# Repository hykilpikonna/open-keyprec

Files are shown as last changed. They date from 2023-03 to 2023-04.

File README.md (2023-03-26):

<h1 align="center">
  <br>
  <br>
  Open-KeyPrec
  <h4 align="center">
  Open-Sourced Electric Keyboard Percussion Instrument
  </h4>
  <h5 align="center">
<a href="#code">Code</a>&nbsp;&nbsp;
<a href="#build">Build</a>&nbsp;&nbsp;
<a href="#usage">Usage</a>&nbsp;&nbsp;
<a href="#license">License</a>
</h5>
  <br>
  <br>
  <br>
</h1>

## About

Open-KeyPrec is an open-sourced, pressure-sensitive electric keyboard percussion (mallet) MIDI instrument. It has 61 keys, spanning 5 octaves of playing range from C2 to C7 like a standard Marimba. It also has a MIDI control panel with 16 buttons, 12 knobs (8 × 280° potentiometers and 4 × 360° rotary encoders).

The sensors are controlled by a development board, and the output is converted into a standard MIDI device. You can use audio workstation softwares like GarageBand or Reaper (or open-source alternatives like LMMS, Zrythm, or Ardour) to simulate the sounds of all kinds of different instruments.

## Code

**Source code structure**

* `/src` - PC driver written in Rust
* `/firmware` - Development board firmware written in C++
* `/circuits` - Printed circuit boards
* `/models` - 3D-printable models

**Toolchains & Environments Used**

* EasyEDA: Web-editor for creating circuit boards
* FreeCAD: Software for designing mechanical 3D models
* CLion: IDE for Rust & C++
* PlatformIO: Firmware development toolkit

**Pin Configuration**

| Pins | I/O | Description |
|---|-----|---|
| 4 | O | Mux Select for C2-B6 |
| 5 | IA  | Mux Input for C2-B6 |
| 1 | IA  | Input for C7 |
| 8 | I | (Panel) Input for 4 rotary encoders |
| 3 | O | Mux Select for buttons and potentiometers |
| 2 | I | Mux Input for buttons |
| 1 | IA  | Mux Input for potentiometers |
| 3 | O | RGB LED Control |

Total ADC channels required: 7
Total GPIO required: 23

## Build

### Materials Required

!!!!!!!!!! TODO !!!!!!!!!!

### Tools Required

* FDM 3D Printer (~$300 Ender 3 is fine)
* Soldering kit (iron, solder, flux)
* Wood Saw
* A computer

### 1. Order PCBs

I ordered my PCBs from JLC, but any PCB service would work. They should accept the exported Gerber zip files in `circuits/Exports` folder.

I created two circuit boards for this keyboard, one is the multiplexer ([Mux v2.zip](circuits/Mux%20v2.zip)) which uses the CD74HC4067 1:16 multiplexer ic to convert the 61 separate analog inputs requirement into only 5 analog inputs and 4 digital switch outputs. 
It also haso diodes and resistors for voltage protection. The other pcb ([OKP-Panel-SMT.zip](circuits/OKP-Panel-SMT.zip)) is for the MIDI control panel containing the buttons and knobs.

1. Go to jlcpcb.com (Or jlc.com if you read Chinese)
2. Upload the Gerber file
3. Set parameters: FR-4, 2 Layers, Color, leave default for other options

**PCB Assembly (SMT)**

If you're not comfortable soldering small SMD components, you can order PCB Assembly from JLC. 
You can also select which parts you would like to SMT based on your soldering abilities. 
For example, in the Mux pcb, I ordered SMT for only the 0603 Zener diodes and the CD74HC4067 ic, and hand-soldered everything else.

1. Order "PCB Assembly" (SMT) and click confirm
2. In the SMT menu, upload the BOM and CPL (PickAndPlace) files
3. After uploading, remove the parts you want to manually solder (they're pretty expensive, since someone in the factory still have to manually solder them for you)
4. Order manually-soldered parts somewhere else (e.g. szlcsc.com)

## Usage

### Flash Firmware

1. Install PlatformIO Core ([Guide](https://platformio.org/install/cli))
2. Open the `firmware` directory
3. In your preferred IDE, edit `src/config.h` with your pin configuration.
4. Edit `platformio.ini` to match your dev board.
5. Connect dev board, build and upload firmware using `platformio run --target upload`

### Setup MIDI Device

!!!!!!!!!! TODO !!!!!!!!!!

### Setup Audio Softwares

A MIDI keyboard doesn't make sound on its own. To actually play an instrument, you would need an audio workstation software and some VST sound sources.

Notation: 🍎 - macOS, 🪟 - Windows, 🐧 - Linux

#### Free Mallet Sound Sources

**Built-in Sources**

* GarageBand comes with marimba, vibraphone, and glockenspiel sound sources. It's free but macOS only and does not have VST support.
* LMMS comes with several mallet instruments.

**External Plugins**

| Name & Link | Author | Platforms | Formats |
| --- | --- | --- | --- |
| [Alto Glockenspiel](https://www.steinberg.net/vst-instruments/alto-glockenspiel/) | Steinberg | 🍎 🪟 | VST, AU |
| [Marimbaphonic](http://www.alanvista.com/marimbaphonic/) | Alan Vista | 🍎 🪟 | VST, AU |
| [VibroMaster](http://www.alanvista.com/vibromaster/) | Alan Vista | 🍎 🪟 | VST, AU |
| [DSK Virtuoso](https://www.dskmusic.com/dsk-virtuoso/) (Celesta, Glockenspiel, ...) | DSK Music | 🪟 | VST |

Unfortunately there aren't any free VSTs supporting linux that I can find. You have to use Windows for this one if you don't have a mac/hackintosh. If you found any additional VSTs, feel free to make a PR!

Other free VST Plugins: https://github.com/webprofusion/OpenAudio

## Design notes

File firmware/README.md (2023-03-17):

## Run

### View logs

* `screen /dev/cu.usbserial-142140 9600`
* Use `↓Ctrl ↓a ↑a ↓\ ↑\` to exit.

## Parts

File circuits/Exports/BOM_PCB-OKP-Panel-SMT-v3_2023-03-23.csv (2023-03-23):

ID | Name | Designator | Footprint | Quantity | Manufacturer Part | Manufacturer | Supplier | Supplier Part | Price | Pins | 3DModel | Contributor | Resistance (Ohms) | description | image | link
1 | 74HC4051PW,118 | BTN-MUXC,BTN-MUXC1,P-MUX | TSSOP-16_L5.0-W4.4-P0.65-LS6.4-BL | 3 | 74HC4051PW,118 |  | LCSC | C5645 | 0.027 | 16 | TSSOP-16_L5.0-W4.4-H1.0-LS6.4-P0.65 | lcsc |  | 8-Channel Analog MultiplexerDemultiplexer |  | https://item.szlcsc.com/6534.html
2 | XL-5050RGBC-WS2812B | LED1,LED2,LED3,LED4,LED9,LED10,LED11,LED12,LED13,LED14,LED15,LED16,LED17,LED18,LED19,LED20,LED21,LED22,LED23,LED24 | LED-SMD_4P-L5.0-W5.0-BL_XL-5050RGBC | 20 |  |  | LCSC | C2843785 | 0.008 | 4 | LED-SMD_4P-L5.0-W5.0-BL_XL-5050RGBC | LCSC |  |  |  | https://atta.szlcsc.com/upload/public/pdf/source/20210708/C2843785_2CEFABF204E2EF27FCE5F6F9FD929633.pdf
3 | KEY-TH_4P-L6.0-W6.0-P4.50-LS6.5 | KEY5,KEY6,KEY7,KEY8 | KEY-TH_4P-L6.0-W6.0-P4.50-LS6.5 | 4 | K2-1102DP-E4SW-04 | 韩国韩荣 | LCSC | C136684 | 0.007 | 4 | KEY-TH_4P-L6.0-W6.0-P4.50-LS6.5 | lcsc |  |  |  | https://item.szlcsc.com/111374.html
4 | K4-6×6_TH | B1,B2,B3,B4,B5,B6,B7,B8 | KEY-TH_4P-L6.0-W6.0-P4.50-LS6.5 | 8 | K2-1102DP-E4SW-04 | 韩国韩荣 | LCSC | C136684 | 0.007 | 4 | KEY-TH_4P-L6.0-W6.0-P4.50-LS6.5 | LCEDA_Lib |  |  |  | https://item.szlcsc.com/111374.html
5 | B3F-4055 | KEY1,KEY2,KEY3,KEY4 | KEY-TH_4P-L12.0-W12.0-P5.00-LS13.4-EH | 4 | B3F-4055 | OMRON(欧姆龙) | LCSC | C84931 | 0.015 | 4 | KEY-TH_4P-L12.0-W12.0-H7.5-LS12.5-P5.0 | lcsc |  |  |  | https://item.szlcsc.com/84377.html
6 | 10kΩ | P1,P2,P3,P4,P5,P6,P7,P8 | RES-ADJ-TH_RK09D1130C4G | 8 | RK09D113000F | ALPSALPINE(阿尔卑斯阿尔派) | LCSC | C470317 | 0.088 | 5 | RES-ADJ-TH_RK09D1130C4G | lcsc |  |  |  | https://atta.szlcsc.com/upload/public/pdf/source/20210222/C2687325_4FFD17AAA104A4955DD1E89BBAB92083.pdf
7 | HDR-M-2.54_1x2 | POWER(5V),POWER2 | HDR-M-2.54_1X2 | 2 |  |  | LCSC | C124375 | 0.004 | 2 | HDR-M-2.54_1x2 | LCEDA_Lib
8 | HDR-M-2.54_2x4 | ROTERY | HDR-M-2.54_2X4 | 1 |  |  | LCSC | C58363 |  | 8 | HDR-M-2.54_2x4 | LCEDA_Lib
9 | EC12E24204A8 | SW1,SW2,SW3,SW4 | SW-TH_EC12EXXXX | 4 | EC12E24204A8 | ALPSALPINE(阿尔卑斯阿尔派) | LCSC | C470598 | 0.091 | 5 | SW-TH_EC12EXXXX-L13.2-W12.4-H20.0-P2.5-LS14.0 | LCSC |  |  |  | https://item.szlcsc.com/476763.html?ref=editor&logined=true
10 | HDR-M-2.54_2x3 | MUX-SEL | HDR-M-2.54_2X3 | 1 |  |  | LCSC | C65114 | 0.005 | 6 | HDR-M-2.54_2x3 | LCEDA_Lib
11 | 10kΩ | PU1,PU2,PU3,PU4,PU5,PU6,PU7,PU8,R1,R2 | R0603 | 10 |  |  | LCSC |  |  | 2 | R0603_L1.6-W0.8-H0.8 | LCSC |  |  |  | https://item.szlcsc.com/137208.html
12 | 1Ω | QWQ | R0603 | 1 | MF1/4W-200KΩ±1% T | CCO(千志电子) | LCSC | C119373 | 0.002 | 2 | R0603_L1.6-W0.8-H0.8 | LCSC | 200K |  |  | https://item.szlcsc.com/137208.html
13 | 1kΩ | R3 | R0603 | 1 |  |  | LCSC |  |  | 2 | R0603_L1.6-W0.8-H0.8 | LCSC |  |  |  | https://item.szlcsc.com/137208.html
14 | 3.3kΩ | R4 | R0603 | 1 |  |  | LCSC |  |  | 2 | R0603_L1.6-W0.8-H0.8 | LCSC |  |  |  | https://item.szlcsc.com/137208.html
15 | HDR-M-2.54_1x3 | LED | HDR-M-2.54_1X3 | 1 |  |  | LCSC | C180248 | 0.031 | 3 | HDR-M-2.54_1x3 | LCEDA_Lib

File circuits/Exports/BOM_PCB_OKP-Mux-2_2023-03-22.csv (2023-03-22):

ID | Name | Designator | Footprint | Quantity | Manufacturer Part | Manufacturer | Supplier | Supplier Part | Price | Pins | 3DModel | Contributor | Resistance (Ohms) | link
1 | HDR-M-2.54_1x2 | OUT1,OUT | HDR-M-2.54_1X2 | 2 |  |  | LCSC | C124375 | 0.004 | 2 | HDR-M-2.54_1x2 | LCEDA_Lib
2 | M1250V-02P | A,A#,B,C,C#,D,D#,E,EX1,EX2,EX3,EX4,F,F#,G,G# | CONN-TH_2P-P1.25_HCTL_HC-1.25-2AW | 16 | M1250V-02P | XFCN(兴飞) | LCSC | C481432 | 0.002 | 2 | CONN-TH_2P-P1.25_HCTL_HC-1.25-2AW | LCSC |  | https://atta.szlcsc.com/upload/public/pdf/source/20210729/C2845535_17B4C65D5133EDBE0A07B8E05D9E3662.pdf
3 | 5.1v | D9,D10,D11,D12,D13,D14,D15,D16,D1,D2,D3,D4,D5,D6,D7,D8 | SOD-123_L2.8-W1.8-LS3.7-RD | 16 | 1N4007W | BLUE ROCKET | LCSC | C328592 | 0.001 | 2 | SOD-123_L2.8-W1.8-LS3.7-RD | LCEDA_Lib |  | https://item.szlcsc.com/301422.html
4 | HDR-M-2.54_1x6 | SEL-NEXT,SEL-PREV | HDR-M-2.54_1X6 | 2 |  |  | LCSC | C190819 | 0.006 | 6 | HDR-M-2.54_1x6 | LCEDA_Lib
5 | CD74HC4067M96 | UWU | SOIC-24_L15.4-W7.5-P1.27-LS10.3-BL | 1 | CD74HC4067M96 | TI(德州仪器) | LCSC | C496123 | 0.163 | 24 | SOIC-24_L15.4-W7.5-H2.7-LS10.3-P1.27 | LCSC |  | https://item.szlcsc.com/417060.html
6 | 47kΩ | R1,R2 | RES-TH_BD2.2-L6.5-P10.50-D0.6 | 2 | MF1/4W-47KΩ±1% T | CCO(千志电子) | LCSC | C119362 | 0.002 | 2 | RES-TH_BD2.2-L6.5-P10.50 | LCSC | 47K | https://item.szlcsc.com/59661.html

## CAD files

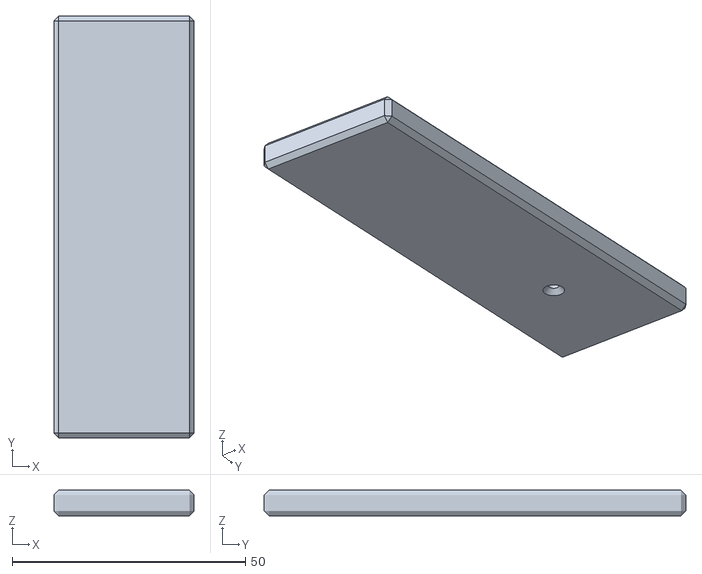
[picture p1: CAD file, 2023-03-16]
models/Exports/50-C#6.stl
30.0 x 90.3 x 5.50

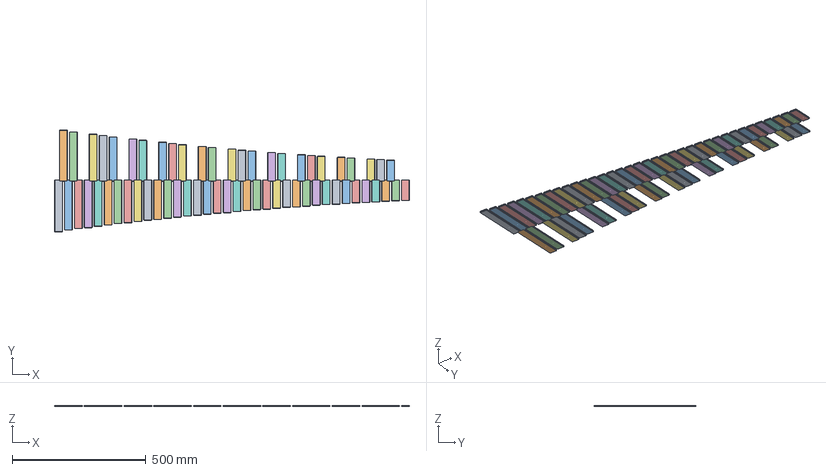
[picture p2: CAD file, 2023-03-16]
models/v4-filled.FCStd
1325.0 x 379.1 x 5.50 mm
C2-Base
C#2-Base
D2-Base
D#2-Base
E2-Base
F2-Base
F#2-Base
G2-Base
G#2-Base
A2-Base
A#2-Base
B2-Base
C3-Base
C#3-Base
D3-Base
D#3-Base
E3-Base
F3-Base
F#3-Base
G3-Base
G#3-Base
A3-Base
A#3-Base
B3-Base
C4-Base
C#4-Base
D4-Base
D#4-Base
E4-Base
F4-Base
F#4-Base
G4-Base
G#4-Base
A4-Base
A#4-Base
B4-Base
C5-Base
C#5-Base
D5-Base
D#5-Base
E5-Base
F5-Base
F#5-Base
G5-Base
G#5-Base
A5-Base
A#5-Base
B5-Base
C6-Base
C#6-Base
D6-Base
D#6-Base
E6-Base
F6-Base
F#6-Base
G6-Base
G#6-Base
A6-Base
A#6-Base
B6-Base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

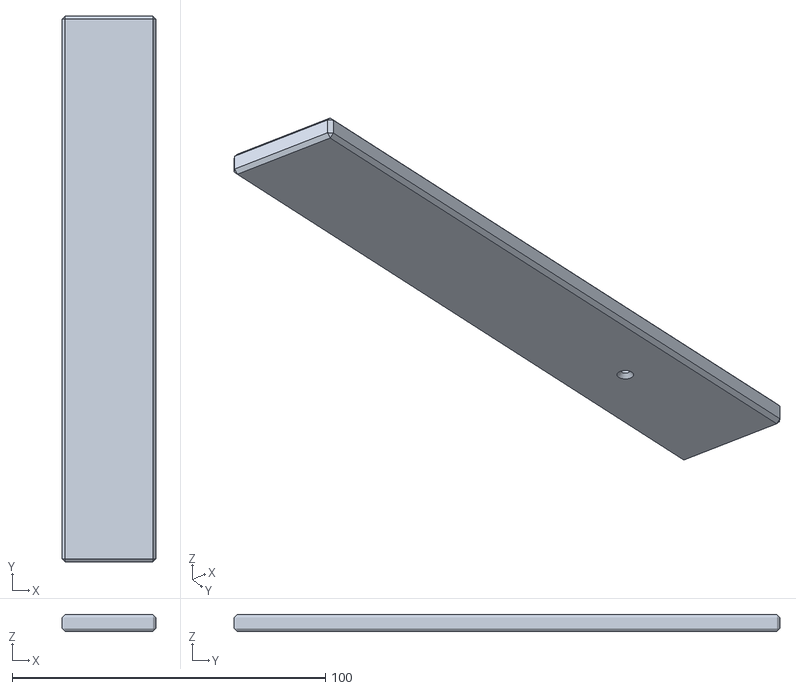
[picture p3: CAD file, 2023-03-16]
models/Exports/08-G2.stl
30.0 x 174.3 x 5.50

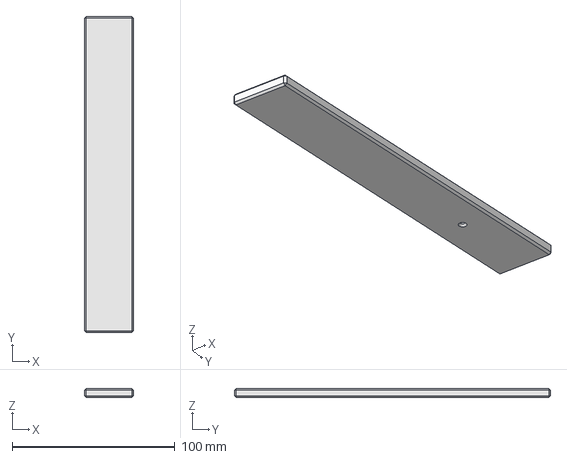
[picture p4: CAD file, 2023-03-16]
models/v4.FCStd
30.0 x 194.0 x 5.50 mm

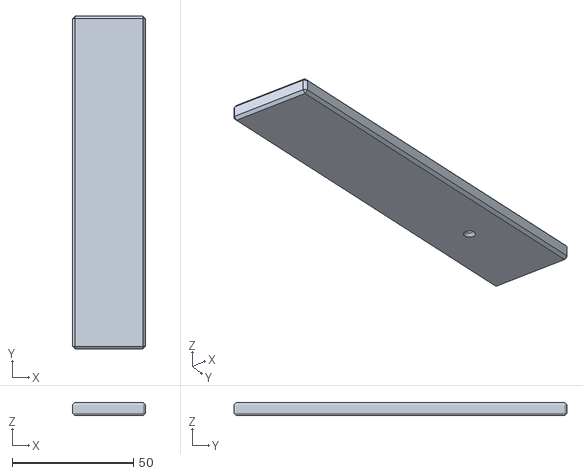
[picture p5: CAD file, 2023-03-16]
models/Exports/23-A#3.stl
30.0 x 137.6 x 5.50

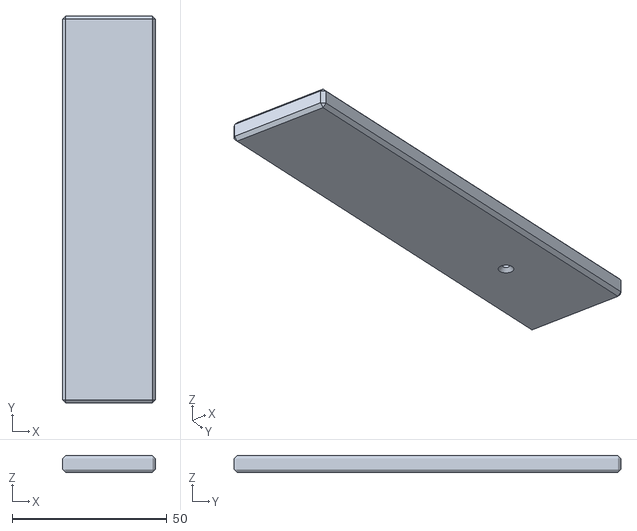
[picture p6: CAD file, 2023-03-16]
models/Exports/29-E4.stl
30.0 x 125.0 x 5.50

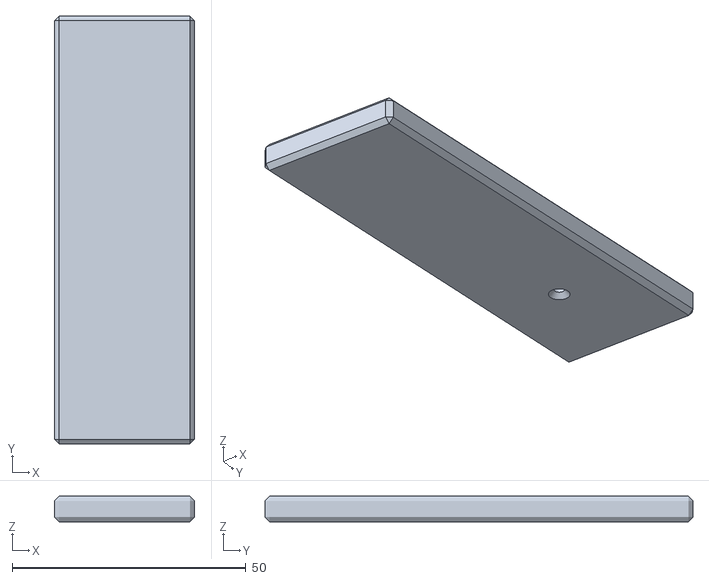
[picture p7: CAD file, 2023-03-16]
models/Exports/49-C6.stl
30.0 x 91.6 x 5.50

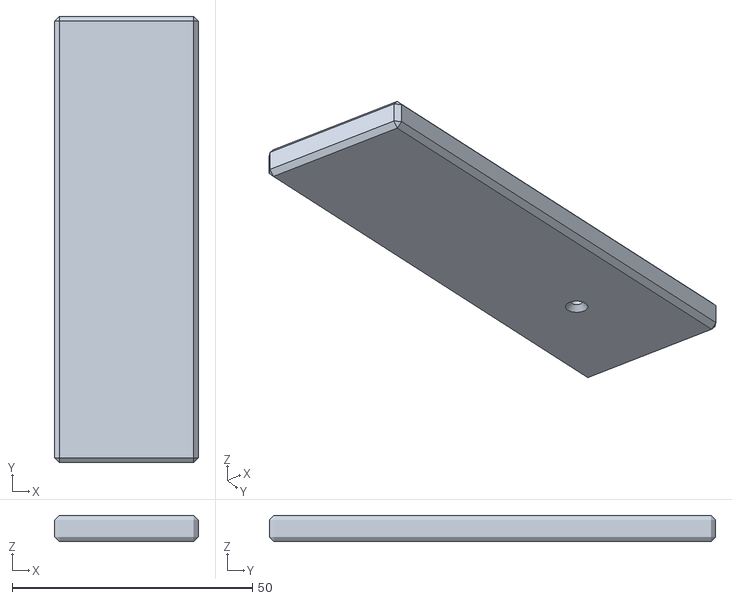
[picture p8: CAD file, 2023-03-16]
models/Exports/48-B5.stl
30.0 x 93.0 x 5.50

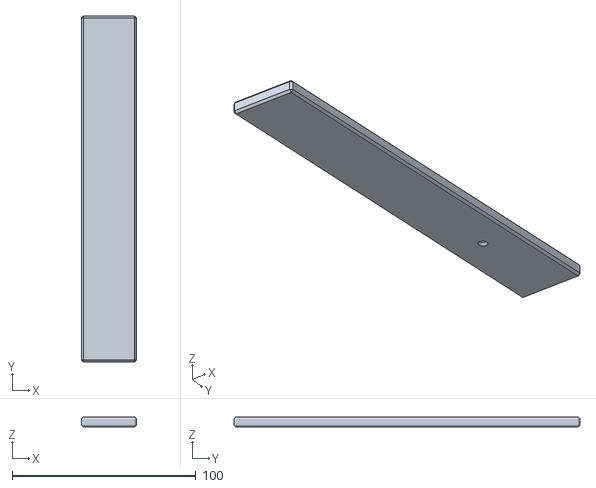
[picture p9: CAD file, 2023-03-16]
models/Exports/03-D2.stl
30.0 x 188.2 x 5.50

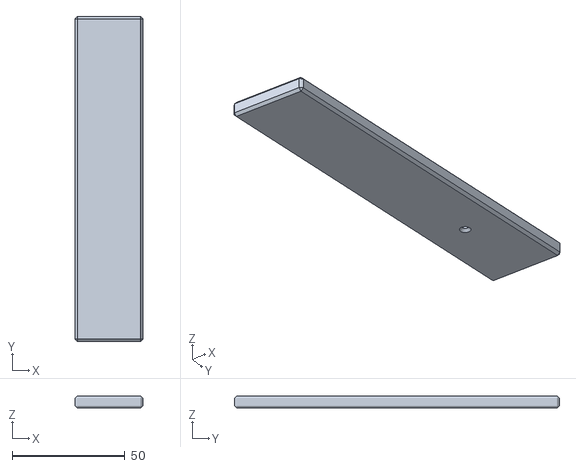
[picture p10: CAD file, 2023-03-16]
models/Exports/20-G3.stl
30.0 x 144.3 x 5.50

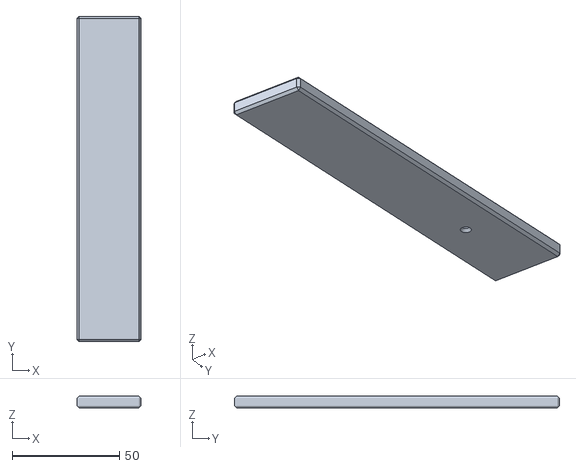
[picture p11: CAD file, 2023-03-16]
models/Exports/17-E3.stl
30.0 x 151.4 x 5.50

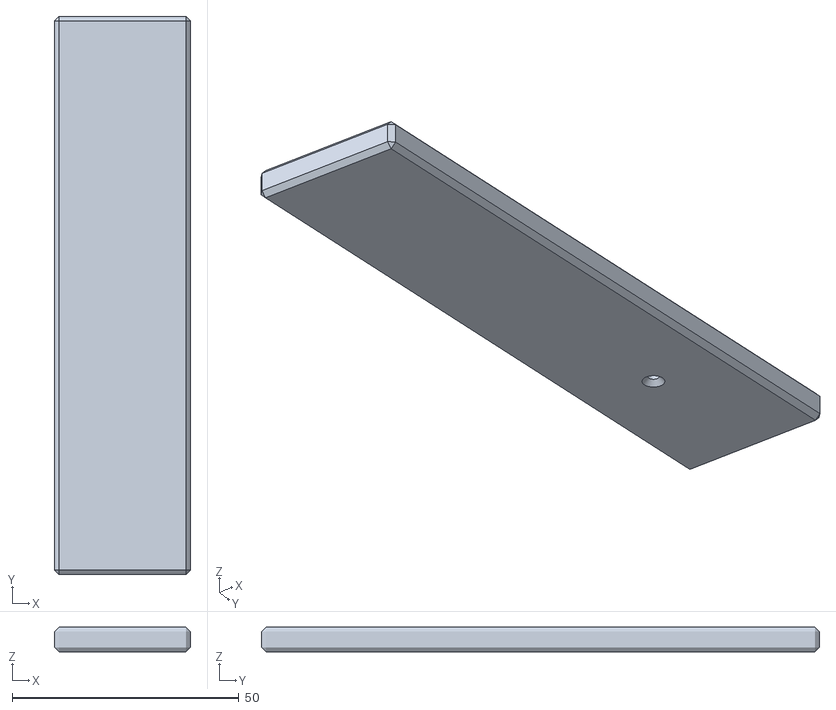
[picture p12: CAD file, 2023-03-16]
models/Exports/30-F4.stl
30.0 x 123.0 x 5.50

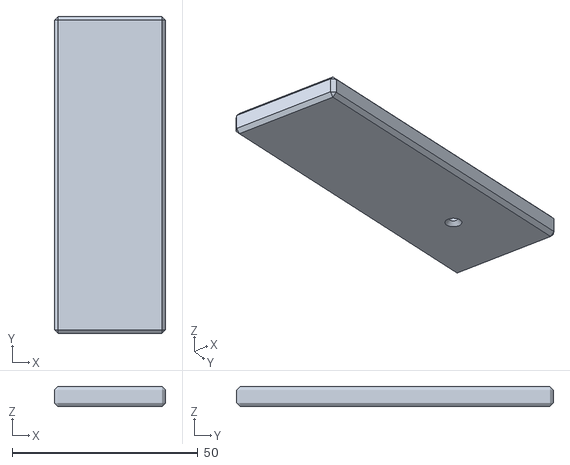
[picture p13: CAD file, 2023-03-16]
models/Exports/54-F6.stl
30.0 x 85.4 x 5.50

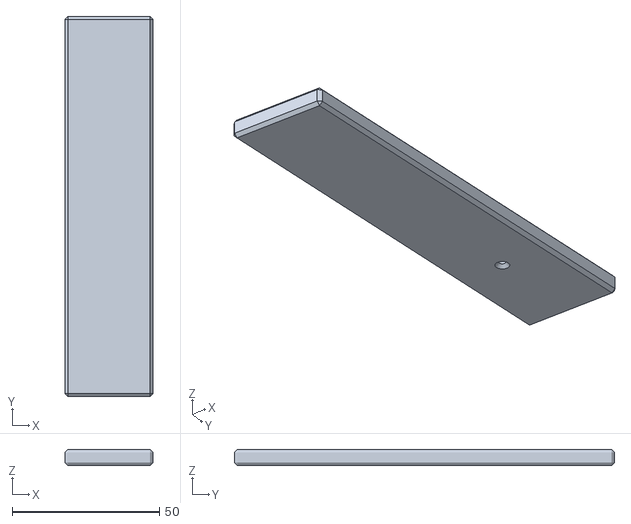
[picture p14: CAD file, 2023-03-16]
models/Exports/27-D4.stl
30.0 x 129.1 x 5.50

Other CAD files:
models/Exports/09-G#2.stl
models/Exports/45-G#5.stl
models/Exports/42-F5.stl
models/Exports/22-A3.stl
models/Exports/01-C2.stl
models/Exports/02-C#2.stl
models/Exports/04-D#2.stl
models/Exports/05-E2.stl
models/Exports/06-F2.stl
models/Exports/07-F#2.stl
models/Exports/10-A2.stl
models/Exports/11-A#2.stl
models/Exports/12-B2.stl
models/Exports/13-C3.stl
models/Exports/14-C#3.stl
models/Exports/15-D3.stl
models/Exports/16-D#3.stl
models/Exports/18-F3.stl
models/Exports/19-F#3.stl
models/Exports/21-G#3.stl
models/Exports/24-B3.stl
models/Exports/25-C4.stl
models/Exports/26-C#4.stl
models/Exports/28-D#4.stl
models/Exports/31-F#4.stl
models/Exports/32-G4.stl
models/Exports/33-G#4.stl
models/Exports/34-A4.stl
models/Exports/35-A#4.stl
models/Exports/36-B4.stl
models/Exports/37-C5.stl
models/Exports/38-C#5.stl
models/Exports/39-D5.stl
models/Exports/40-D#5.stl
models/Exports/41-E5.stl
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

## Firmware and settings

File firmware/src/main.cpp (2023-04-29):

#include <Arduino.h>
#include "config.h"
#include "Adafruit_NeoPixel.h"
#include "main.h"
#include "utils.h"
#include "panel.cpp"
#include "keyboard_lights.cpp"

u32 lasts[NUM_NOTES];  // variable to store the value coming from the sensor
u64 last_hit_times[NUM_NOTES];
u32 bounce_delay = 50; // Minimum time between two hits

let max_sensor = 4096;
let max_threshold = 3000;
let active_threshold = 400;  // Minimum value to be considered as a hit

let led_refresh_on = false;

Panel panel;
KeyboardLights keyboardLights;

void setup()
{
    // Initialize pins
    pinModeSafe(LED_REFRESH, OUTPUT);
    for (int pin: MUX_IN) pinModeSafe(pin, INPUT);
    for (int pin: MUX_SEL_OUT) pinModeSafe(pin, OUTPUT);

    // Initialize serial
    Serial.begin(115200);
    Serial.printf("Initialized\r\n");

    panel.begin();
    keyboardLights.begin();
}

u64 fps_last_update = 0;
u32 fps_updates = 0;
const u32 fps_interval_ms = 1000;

void countFps(u64 time)
{
    // Report FPS every second
    fps_updates++;
    if (time - fps_last_update >= fps_interval_ms)
    {
        fps_last_update = time;
        double fps = 1.0 * fps_updates / fps_interval_ms * 1000;
        Serial.printf("FPS: %.2f\r\n", fps);
        fps_updates = 0;
    }
}

void readKeyboard()
{
    u64 time = millis();
    countFps(time);

    // Toggle LED refresh indicator
    digitalWrite(LED_REFRESH, led_refresh_on = !led_refresh_on);

    // Loop through each multiplexer state
    for (int i = 0; i < PINS_PER_MUX; i++)
    {
        // Set select pins
        for (int j = 0; j < NUM_MUX_SEL; j++)
        {
            // i >> j is the jth bit of i
            digitalWrite(MUX_SEL_OUT[j], (i >> j) & 1);
        }

        // Read input pins from the multiplexer
        for (int j = 0; j < NUM_MUX; j++)
        {
            int note_id = j * PINS_PER_MUX + i;
            if (note_id >= NUM_NOTES) break;

            // Read the analog input
            u32 v = analogRead(MUX_IN[j]);
            if (v != lasts[note_id])
            {
                on_sensor_update(note_id, time, lasts[note_id], v);
            }
            lasts[note_id] = v;
        }
    }
}

/**
 * Called when the sensor value changes
 *
 * @param id Sensor index
 */
void on_sensor_update(int id, u64 time, u32 last, u32 current)
{
    // If the last hit is too close, ignore this hit
    let last_hit_time = last_hit_times[id];
    if (time - last_hit_time < bounce_delay) return;

    // If the value is above the threshold
    if (current > active_threshold)
    {
        // If the last value is below the threshold, it's a new hit
        if (last < active_threshold)
        {
            // Send MIDI message
            // /hit <note> <velocity>
            Serial.printf("/hit %d %d\r\n", notes[id].midi,
                          MIN((last - active_threshold) * 127 / (max_threshold - active_threshold), 127));

            // Lights
            keyboardLights.hit(id);
        }
    }
    else if (last > active_threshold)
    {
        // Released
        last_hit_times[id] = time;
    }
}

void loop()
{
    readKeyboard();

//    for (int i = 0; i < LK_NUM_LIGHTS; i++)
//    {
//        lk.setPixelColor(i, Adafruit_NeoPixel::ColorHSV(last_hue + i * hue_interval, 255, brightness));
//    }
}

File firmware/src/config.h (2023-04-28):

#ifndef FIRMWARE_CONFIG_H
#define FIRMWARE_CONFIG_H

#include "utils.h"

// ========================================
// Main Keyboard Pin Configuration
// ========================================

// LED indicator for pulling update
const int LED_REFRESH = 45;

// 4 1:16 Multiplexers: GPIO pins for each analog multiplexer that handles 12 sensors of an octave
// Notes are connected in order: Mux #1 (0-11), Mux #2 (12-23), Mux #3 (24-35), Mux #4 (36-47), Mux #5 (48-59)
const int NUM_MUX = 5;
const int PINS_PER_MUX = 12;
const int MUX_IN[NUM_MUX] = {4, 5, 6, 7, 8};

// Select pins for every multiplexer, each multiplexer has 4 select pins, all sel0 are connected to 14, etc.
const int NUM_MUX_SEL = 4;
const int MUX_SEL_OUT[NUM_MUX_SEL] = {14, 13, 12, 11};

// LED Light strip
const int LK_PIN = 2;
const int LK_LIGHTS_PER_METER = 60;
constexpr float LK_NUM_METERS = 2;
const int LK_KEY_SPACING_MM = 7;
const int LK_KEY_LEN_MM = 30;
const int LK_OFFSET_MM = 25; // Length in mm from the start of the strip to the first key
const float LK_LIGHTS_PER_MM = LK_LIGHTS_PER_METER / 1000.0;
constexpr int LK_NUM_LIGHTS = (int) (LK_LIGHTS_PER_METER * LK_NUM_METERS + 0.5);

// ========================================
// MIDI Panel Pin Configuration
// ========================================

// 3 1:8 Multiplexers for the midi panel
const int P_PINS_PER_MUX = 8;
const int P_KEY_MUX_IN = 36;
const int P_BUTTON_MUX_IN = 35;  // Digital signal inputs for button multiplexers
const int P_KNOB_MUX_IN = 10;  // Analog signal inputs for potentiometer

// Select pins for every multiplexer, each multiplexer has 3 select pins
const int P_NUM_MUX_SEL = 3;
const int P_MUX_SEL_OUT[P_NUM_MUX_SEL] = {37, 38, 39};

// Rotary encoder pins
const int P_NUM_ROTARY = 4;
const int P_ROTARY_A[P_NUM_ROTARY] = {18, 17, 16, 15};
const int P_ROTARY_B[P_NUM_ROTARY] = {19, 20, 21, 47};

// LED light strips
const int P_LED_KEY = 42;
const int P_LED_KNOB = 41;
const int P_LED_ROTARY = 40;

// ========================================
// Constants
// ========================================

typedef struct note
{
    char name[4];
    u16 midi;
} Note;

// 61 Notes from C2 to C7
const int NUM_NOTES = 61;
const int NUM_SHARP_NOTES = 25;
const int NUM_REGULAR_NOTES = NUM_NOTES - NUM_SHARP_NOTES;

const Note notes[] = {
        {"C2", 36}, {"C#2", 37}, {"D2", 38}, {"D#2", 39}, {"E2", 40}, {"F2", 41}, {"F#2", 42}, {"G2", 43}, {"G#2", 44}, {"A2", 45}, {"A#2", 46}, {"B2", 47},
        {"C3", 48}, {"C#3", 49}, {"D3", 50}, {"D#3", 51}, {"E3", 52}, {"F3", 53}, {"F#3", 54}, {"G3", 55}, {"G#3", 56}, {"A3", 57}, {"A#3", 58}, {"B3", 59},
        {"C4", 60}, {"C#4", 61}, {"D4", 62}, {"D#4", 63}, {"E4", 64}, {"F4", 65}, {"F#4", 66}, {"G4", 67}, {"G#4", 68}, {"A4", 69}, {"A#4", 70}, {"B4", 71},
        {"C5", 72}, {"C#5", 73}, {"D5", 74}, {"D#5", 75}, {"E5", 76}, {"F5", 77}, {"F#5", 78}, {"G5", 79}, {"G#5", 80}, {"A5", 81}, {"A#5", 82}, {"B5", 83},
        {"C6", 84}, {"C#6", 85}, {"D6", 86}, {"D#6", 87}, {"E6", 88}, {"F6", 89}, {"F#6", 90}, {"G6", 91}, {"G#6", 92}, {"A6", 93}, {"A#6", 94}, {"B6", 95},
        {"C7", 96}
};

#endif //FIRMWARE_CONFIG_H

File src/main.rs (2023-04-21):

use std::io::{BufRead, BufReader};
use std::process::exit;

use anyhow::Result;
use log::info;
use midir::MidiOutput;
use midir::os::unix::VirtualOutput;

fn start() -> Result<()> {
    let midi_out = MidiOutput::new("MIDI Output")?;
    let mut conn_out = midi_out.create_virtual("Virtual MIDI Output").unwrap();

    // List serial devices
    let ports = serialport::available_ports()?;

    // If there are no ports available, quit
    if ports.is_empty() {
        println!("No serial ports found.");
        exit(0);
    }

    // Let the user choose a port
    println!("Available serial ports:");
    for (i, p) in ports.iter().enumerate() {
        println!("{}: {}", i, p.port_name);
    }
    println!("Choose a port (range 0-{}): ", ports.len() - 1);

    let mut input = String::new();
    std::io::stdin().read_line(&mut input).unwrap();
    let choice = input.trim().parse::<usize>().unwrap();
    let port = &ports[choice];

    // Open serial port
    let serial_port = serialport::new(port.port_name.as_str(), 115200)
        .timeout(std::time::Duration::from_millis(10))
        .open()?;
    let mut reader = BufReader::new(serial_port);

    let mut buf = Vec::new();

    info!("Starting");

    loop {
        match reader.read_until(b'\n', &mut buf) {
            Ok(t) => {
                if t == 0 { continue }

                // Convert buffer to string
                let mut line = String::from_utf8_lossy(&buf).to_string();
                line = line.trim().to_string();
                buf.clear();

                println!("{}", line);

                // Only process commands
                if !line.starts_with("/") { continue }

                // Split command arguments
                let args: Vec<&str> = line.split_whitespace().collect();

                // Command /hit <note> <velocity>
                // Usage example: /hit 60 127
                if args[0] == "/hit" {
                    let note = args[1].parse::<u8>()?;
                    // let note = 72; // c5
                    let velocity = args[2].parse::<u8>()?;
                    conn_out.send(&[0x99, note, velocity]).unwrap();

                    // Since it's an instant hit, we need to send a note off
                    // Sleep for 10ms to make sure the note off is sent after the note on
                    // std::thread::sleep(std::time::Duration::from_millis(10));
                    conn_out.send(&[0x89, note, 0]).unwrap();
                }

                // Command /pedal <0 = off / 1 = on>
                // Usage example: /pedal 0
                if args[0] == "/pedal" {
                    let pedal = args[1].parse::<u8>()? * 127;
                    conn_out.send(&[0xB0, 64, pedal]).unwrap();
                }
            },
            Err(ref e) if e.kind() == std::io::ErrorKind::TimedOut => (),
            Err(e) => {
                if e.kind() == std::io::ErrorKind::BrokenPipe {
                    println!("Connection closed.");
                    exit(0);
                }
            },
        }
    }
}

fn main() {
    pretty_env_logger::init();
    start().expect("Error: Start failed.");
}

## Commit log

2023-03-16 [+] Model of one note
    [v4.FCStd]
2023-03-16 [+] Filled model
    [v4-filled.FCStd]
2023-03-16 [+] Old models and exports
    [testing.FCStd, testing.stl, v2-140.stl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]
2023-03-16 [+] Exports
    [v4-C2.stl, v4-filled_A#2-Base.stl, v4-filled_A#3-Base.stl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]
2023-03-17 [M] Rename models
    [A#2.stl, A#3.stl, A#4.stl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]
2023-03-17 [M] Rename models (again)
    [01-C2.stl, 02-C#2.stl, 03-D2.stl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]
2023-03-18 [+] Implement multi-pin mux select
2023-03-22 [+] Mux circuit
    [BOM_PCB_OKP-Mux-2_2023-03-22.csv, PickAndPlace_PCB_OKP-Mux-2_2023-03-22.csv]
2023-03-23 [+] SMT version of midi panel
    [BOM_PCB-OKP-Panel-SMT-v3_2023-03-23.csv, PickAndPlace_PCB-OKP-Panel-SMT-v3_2023-03-23.csv]
2023-03-24 [U] Update pin layout and threshold
2023-03-25 [O] Try different frameworks
2023-03-26 [+] Pin configuration
2023-03-26 [-] Replace ESP32 with "development board"
2023-03-26 [+] Order pcb instructions
2023-04-10 [O] (Experimental) switch to stm32
2023-04-12 [+] ESP32-S3 Config
2023-04-12 [+] Pin config
2023-04-28 [F] Fix position calculation
    [config.h]
2023-04-28 [+] Update thread
2023-04-29 [O] Optimize: Don't draw unchanged frames
2023-04-29 [F] Fix random hue and optimize last frame detection
